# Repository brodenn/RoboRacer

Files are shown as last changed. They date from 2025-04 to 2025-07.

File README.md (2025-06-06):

# RoboRacer

## 📄 [Download the full report: Report ghost divsion.pdf](./Report%20ghost%20divsion.pdf)

Welcome to the RoboRacer project! This repository contains the full stack for the Omnix robot platform, including embedded firmware, Python-based visualization and configuration tools, and supporting documentation.

---

## Project Images

### Robots
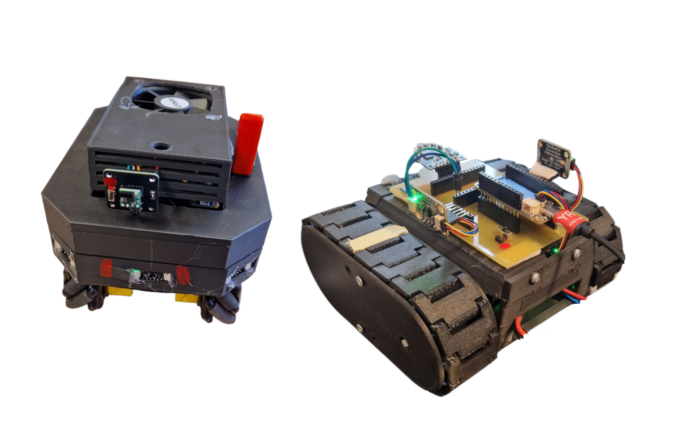
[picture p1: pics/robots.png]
Robots


---

# Omnix Overview

The `omnix` robot is a core vehicle in the RoboRacer project, equipped with omni wheels for enhanced maneuverability. It handles sensor management, motor control, AI steering, and wireless communication, and is supported by a Python toolkit for visualization and configuration.

---

## Directory Structure

- **`ai.cpp` / `ai.h`**: AI steering logic for autonomous navigation.
- **`controller.cpp` / `controller.h`**: Gamepad/controller input management.
- **`globals.cpp` / `globals.h`**: Global variables and constants.
- **`imu.cpp` / `imu.h`**: IMU (Inertial Measurement Unit) initialization and data reading.
- **`interrupts.cpp` / `interrupts.h`**: Sensor interrupt configuration and management.
- **`motors.cpp` / `motors.h`**: Motor initialization and control.
- **`mux.cpp` / `mux.h`**: I2C multiplexer for sensor communication.
- **`params.cpp` / `params.h`**: Steering and sensor parameter management.
- **`sensors.cpp` / `sensors.h`**: Sensor initialization, reading, and management.
- **`tasks.cpp` / `tasks.h`**: FreeRTOS tasks for sensors, motors, and logic.
- **`udp_handler.cpp` / `udp_comm.h`**: UDP communication for parameters and telemetry.
- **`udp_sender.cpp`**: Telemetry data transmission over UDP.
- **`wifi_setup.cpp` / `wifi_setup.h`**: WiFi and UDP setup.
- **`xshut.cpp` / `xshut.h`**: Sensor power control via GPIO.
- **`omnix_py/`**: Python scripts for visualization, configuration, and debugging.

---

## Python Toolkit Overview

The `omnix_py` directory provides Python scripts that complement the robot's firmware:

- **`main.py`**: Entry point for the Python tools (UI and visualizer).
- **`udp_comm.py`**: UDP communication for telemetry and commands.
- **`ui.py`**: Tkinter-based GUI for parameter tuning and monitoring.
- **`visualizer.py`**: Pygame-based visualization of sensor and IMU data.
- **`config.py`**: Shared configuration (ports, IPs, parameters).
- **`logger.py`**: Telemetry and sensor data logging to CSV.

---

## Key Features

- **Omni Wheels**: Smooth, precise movement in any direction.
- **Sensor Management**: Multiple VL53L4CD sensors via I2C multiplexers.
- **Motor Control**: Smooth updates and autonomous driving logic.
- **AI Steering**: Wall centering, curve anticipation, and obstacle avoidance.
- **Wireless Communication**: Real-time telemetry and parameter updates via UDP.
- **IMU Integration**: Acceleration, gyroscope, and temperature data.
- **Python Tools**: UI for parameter tuning and real-time telemetry visualization.

---

## Setup Instructions

1. Initialize the I2C buses and configure the multiplexer.
2. Set up sensors, motors, and WiFi.
3. Start FreeRTOS tasks for sensor reading, motor control, and auxiliary logic.
4. Run the Python tools using `python3 main.py` in the `omnix_py` directory.

---

## Usage

- **Autonomous Mode**: AI steering logic controls the motors based on sensor data.
- **Controller Mode**: Use a gamepad for manual control.
- **Python Tools**: Tune parameters and monitor telemetry in real time.

---

## Dependencies

- [ArduinoJson](https://arduinojson.org/)
- [Adafruit Motor Shield Library](https://github.com/adafruit/Adafruit_Motor_Shield_V2_Library)
- [Adafruit LSM6DSOX Library](https://github.com/adafruit/Adafruit_LSM6DSOX)
- [Bluepad32](https://github.com/ricardoquesada/Bluepad32)
- [VL53L4CD Library](https://github.com/stm32duino/VL53L4CD)
- **Python**: Requires Python 3.8+ with the following libraries:
  - `pygame`
  - `tkinter`
  - `socket`
  - `json`
  - `csv`

---

## Visualizer Example

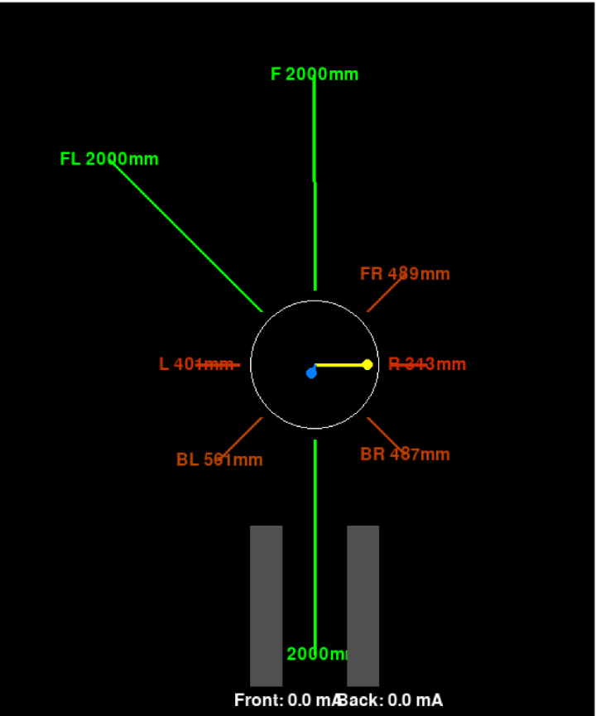
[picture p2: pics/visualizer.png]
Visualizer


---

## Configuration GUI

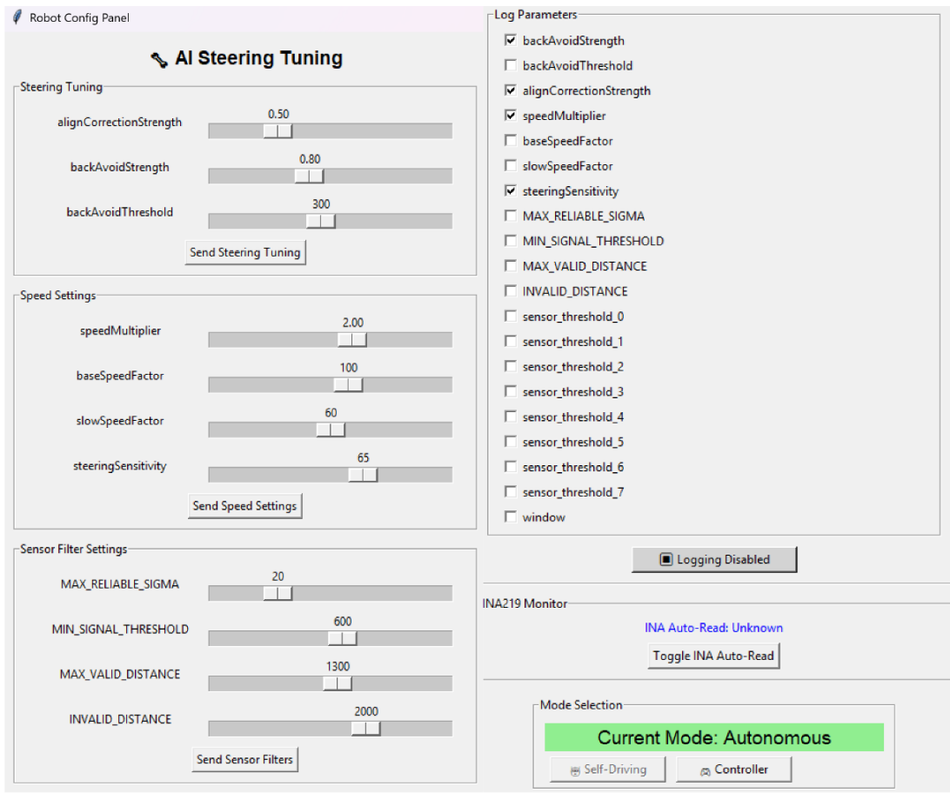
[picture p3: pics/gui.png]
GUI


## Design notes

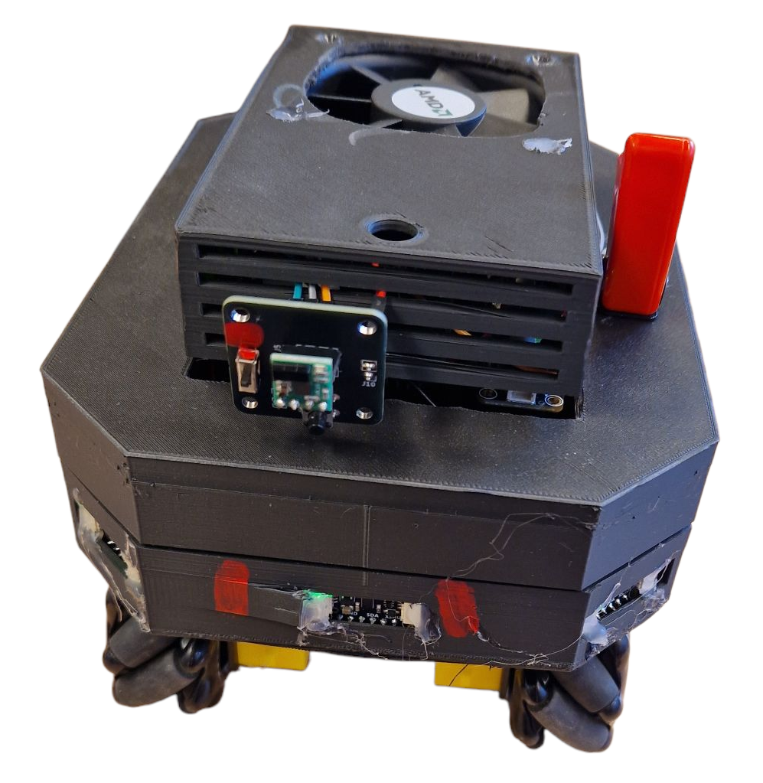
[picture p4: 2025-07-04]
omnix/Omni-X.png

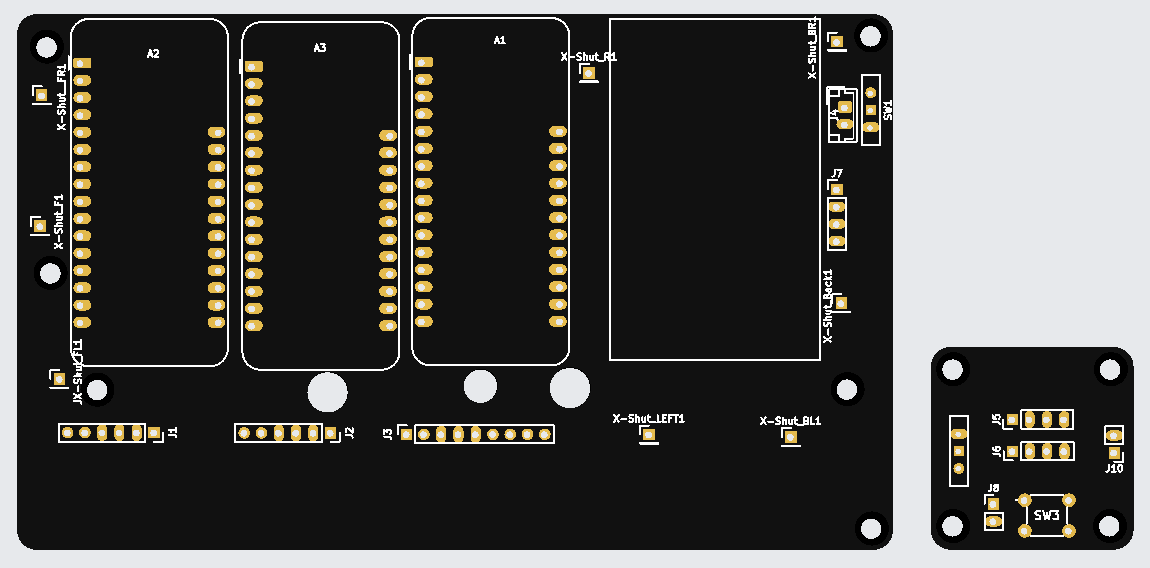
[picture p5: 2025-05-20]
Omni_X-PCB/Screenshot 2025-05-19 212435.png

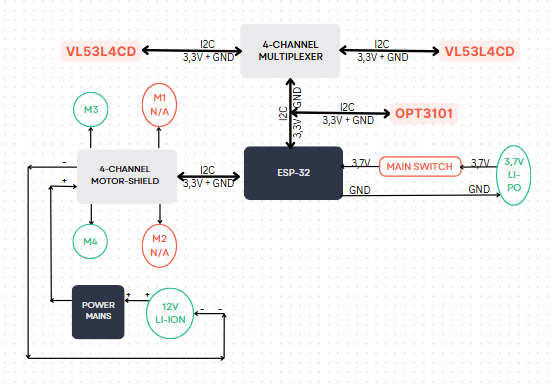
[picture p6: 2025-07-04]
omnix/Panzer_Connection_layout.png

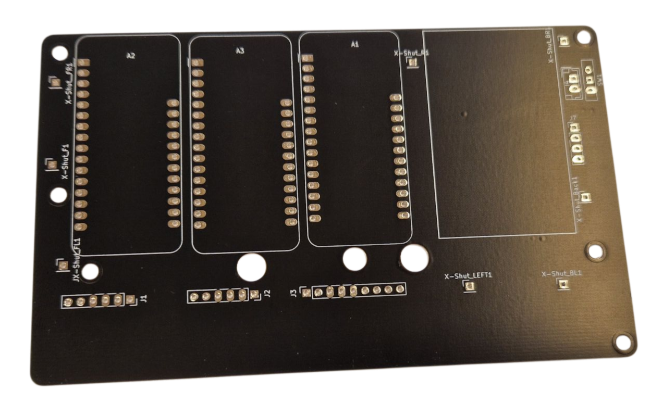
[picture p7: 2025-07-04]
omnix/Omni-X_PCB.png

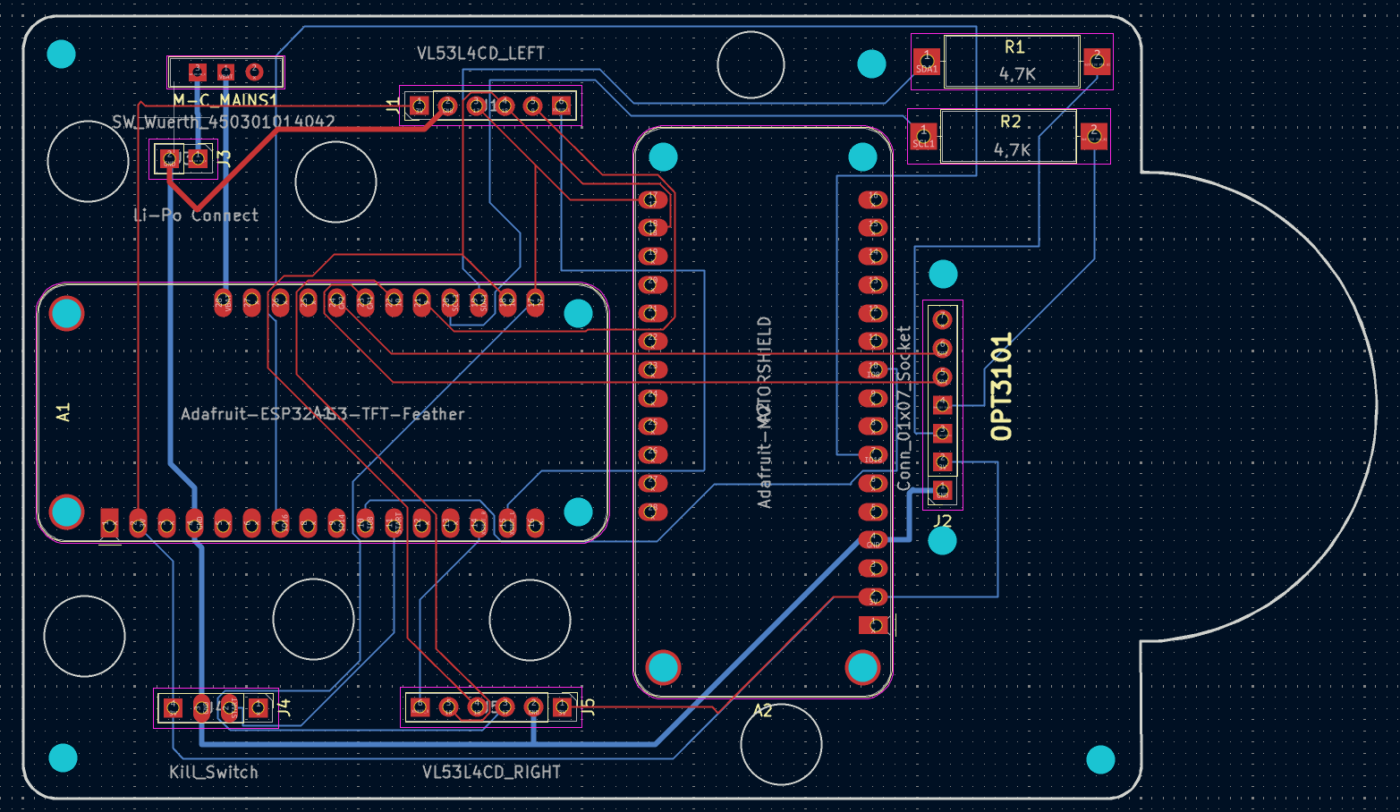
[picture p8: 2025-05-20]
Panzer/Panzer_PCB/Panzer_PCB/Screenshot 2025-05-19 212106.png

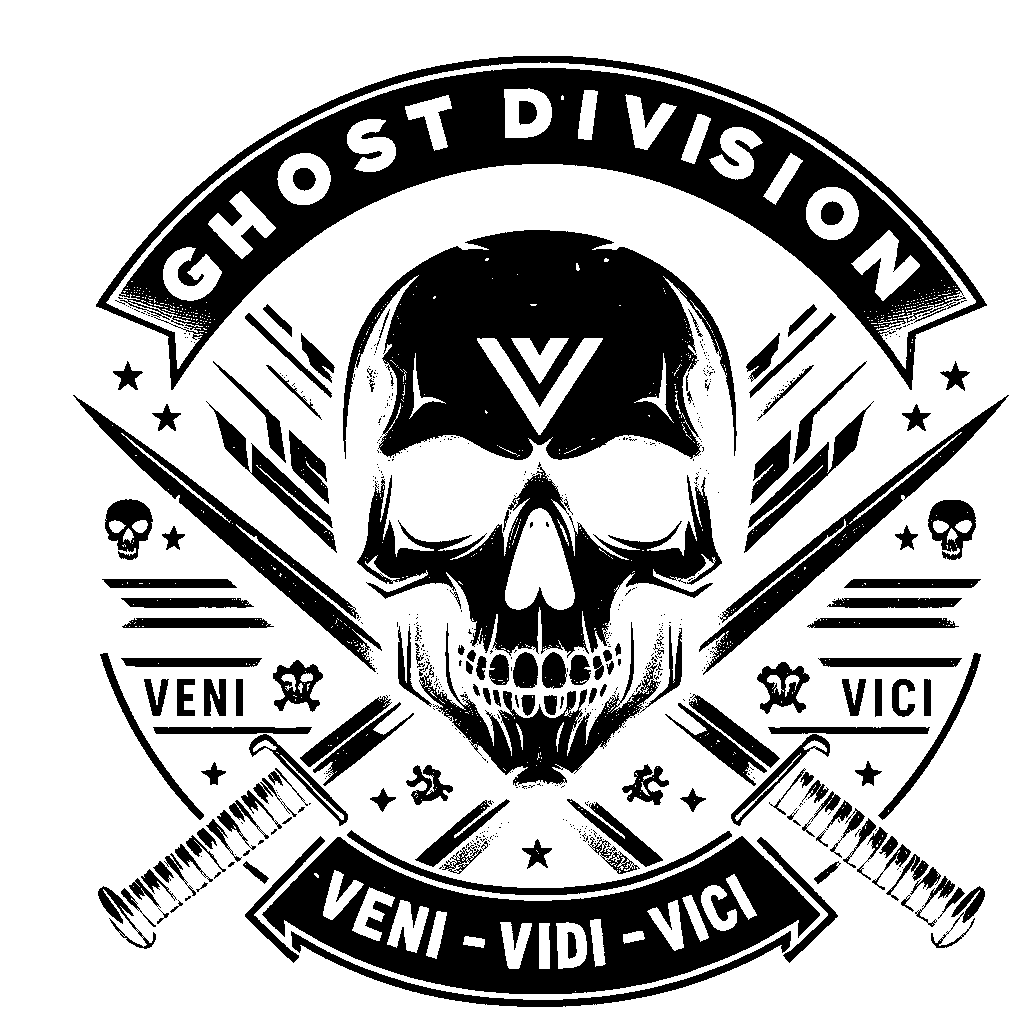
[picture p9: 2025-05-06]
Omni_X-PCB/Omni-X-II-PCB/ghost_division_bw.png

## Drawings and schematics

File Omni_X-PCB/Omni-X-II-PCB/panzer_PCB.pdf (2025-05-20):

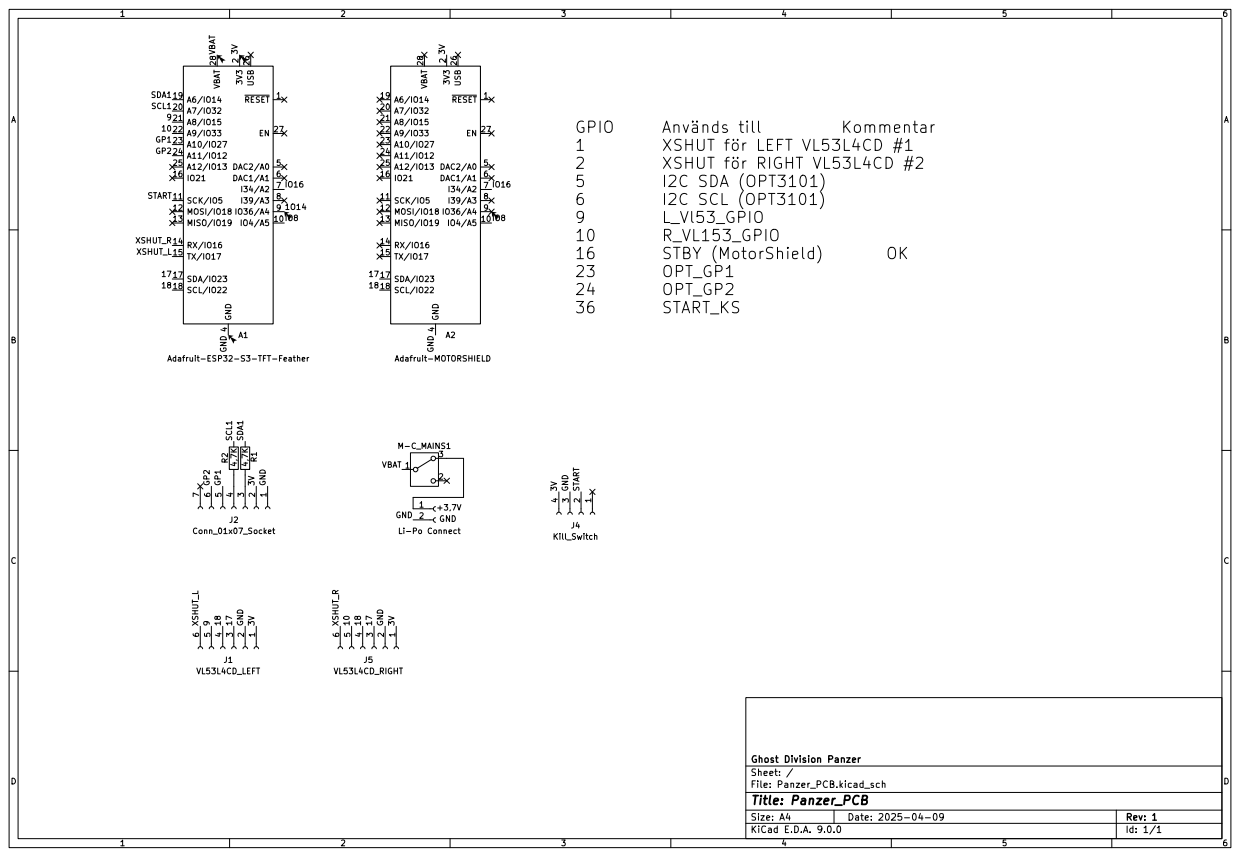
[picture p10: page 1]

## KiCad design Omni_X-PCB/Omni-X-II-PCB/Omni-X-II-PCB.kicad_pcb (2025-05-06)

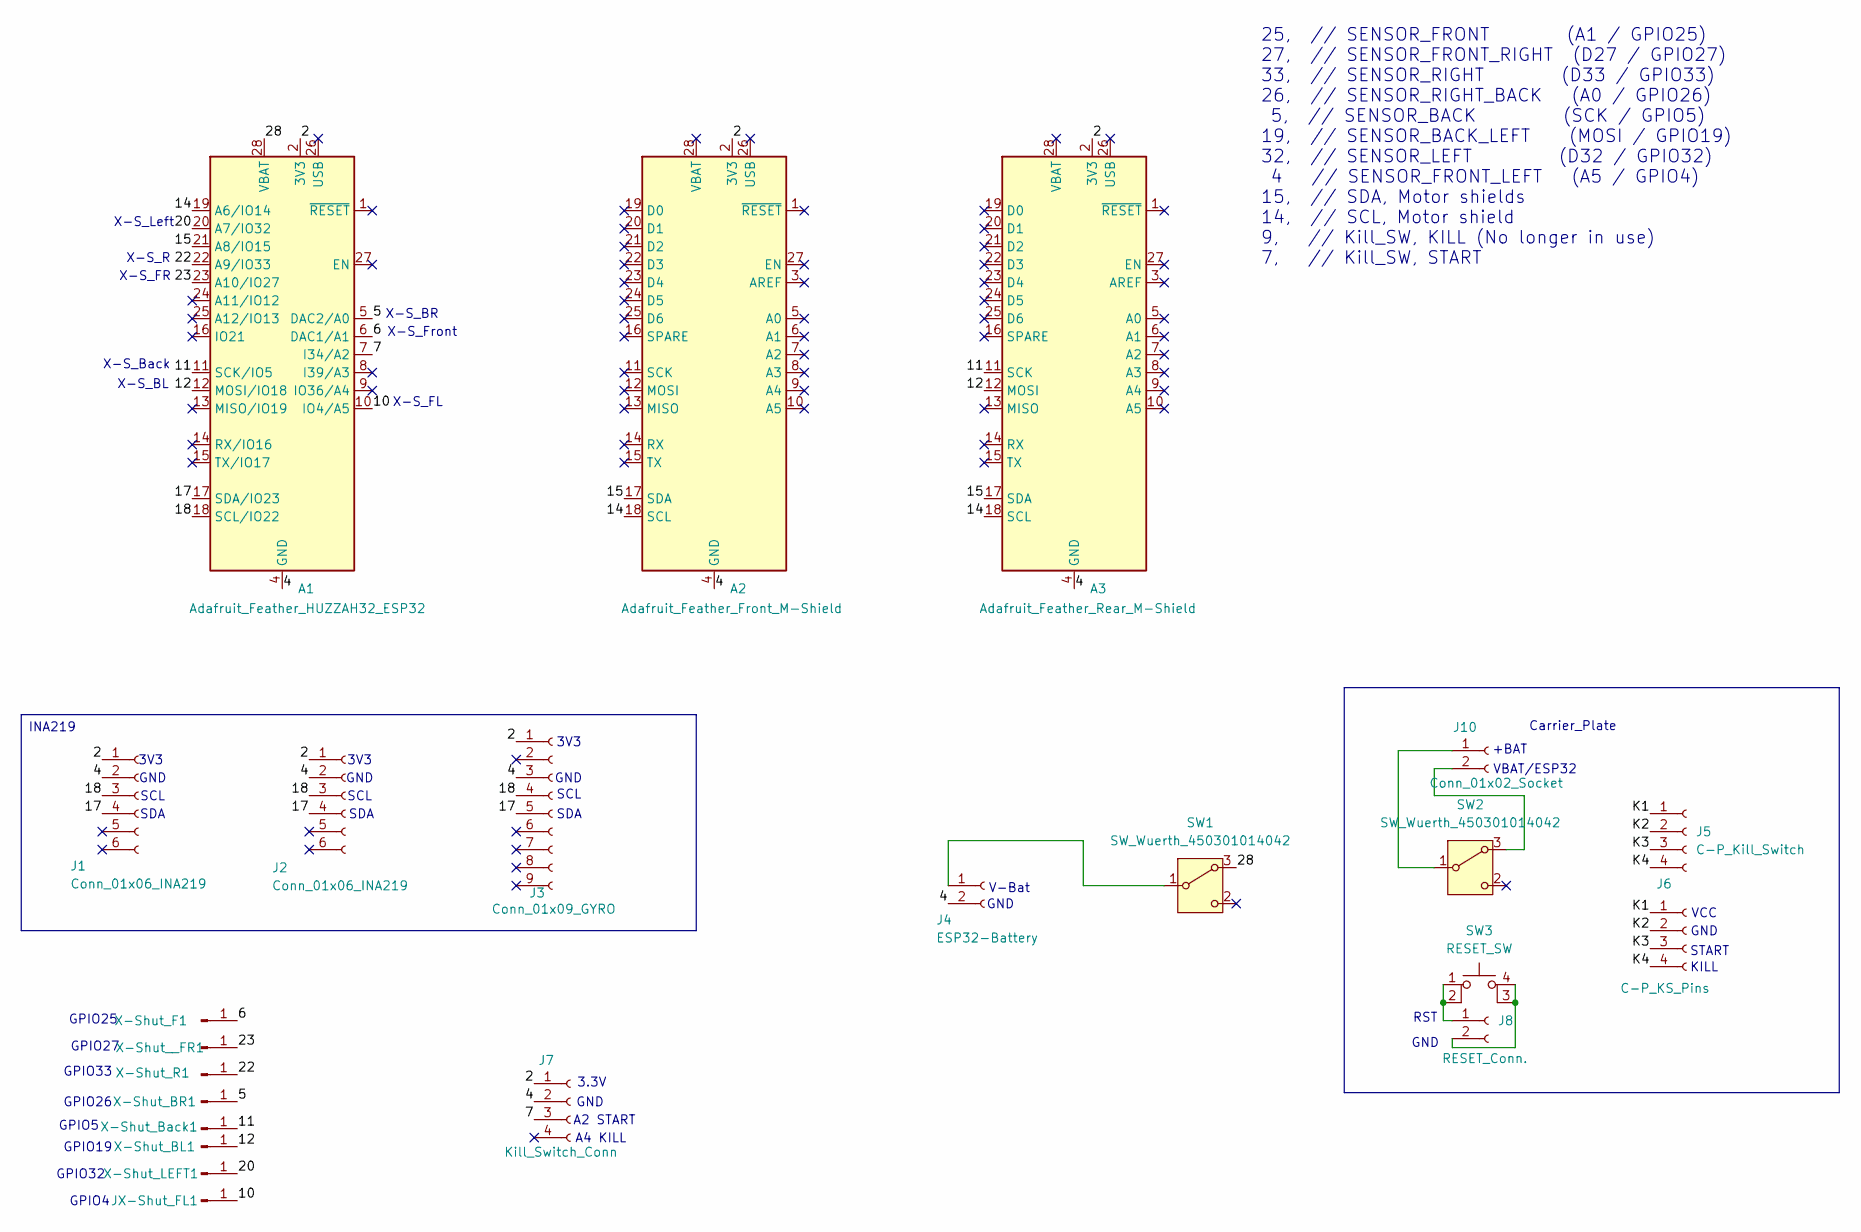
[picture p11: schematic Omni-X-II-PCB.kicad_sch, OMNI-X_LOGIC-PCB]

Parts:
A1: Adafruit_Feather_HUZZAH32_ESP32; Adafruit_Feather
A2: Adafruit_Feather_Front_M-Shield; Adafruit_Feather
A3: Adafruit_Feather_Rear_M-Shield; Adafruit_Feather
J1, J2: Conn_01x06_INA219; PinSocket_1x06_P2.54mm_Vertical
J3: Conn_01x09_GYRO; PinSocket_1x09_P2.54mm_Vertical
J4: ESP32-Battery; JST_EH_B2B-EH-A_1x02_P2.50mm_Vertical
J5: C-P_Kill_Switch; PinHeader_1x04_P2.54mm_Vertical
J6: C-P_KS_Pins; PinHeader_1x04_P2.54mm_Vertical
J7: Kill_Switch_Conn; PinHeader_1x04_P2.54mm_Vertical
J8: RESET_Conn.; PinHeader_1x02_P2.54mm_Vertical
J10: Conn_01x02_Socket; PinHeader_1x02_P2.54mm_Vertical
JX-Shut_FL1: Conn_01x01_Pin; PinHeader_1x01_P2.54mm_Vertical
SW1, SW2: SW_Wuerth_450301014042; SW_Slide-03_Wuerth-WS-SLTV_10x2.5x6.4_P2.54mm
SW3: RESET_SW; Tac_Switch_THT
X-Shut_BL1: Conn_01x01_Pin; PinHeader_1x01_P2.54mm_Vertical
X-Shut_BR1: Conn_01x01_Pin; PinHeader_1x01_P2.54mm_Vertical
X-Shut_Back1: Conn_01x01_Pin; PinHeader_1x01_P2.54mm_Vertical
X-Shut_F1: Conn_01x01_Pin; PinHeader_1x01_P2.54mm_Vertical
X-Shut_LEFT1: Conn_01x01_Pin; PinHeader_1x01_P2.54mm_Vertical
X-Shut_R1: Conn_01x01_Pin; PinHeader_1x01_P2.54mm_Vertical
X-Shut__FR1: Conn_01x01_Pin; PinHeader_1x01_P2.54mm_Vertical

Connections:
/2: A1.2 (3V3), A2.2 (3V3), A3.2 (3V3), J1.1, J2.1, J3.1, J7.1
/4: A1.4 (GND), A2.4 (GND), A3.4 (GND), J1.2, J2.2, J3.3, J4.2, J7.2
/5: A1.5 (DAC2/A0), X-Shut_BR1.1
/6: A1.6 (DAC1/A1), X-Shut_F1.1
/7: A1.7 (I34/A2), J7.3
/10: A1.10 (IO4/A5), JX-Shut_FL1.1
/11: A1.11 (SCK/IO5), A3.11 (SCK), X-Shut_Back1.1
/12: A1.12 (MOSI/IO18), A3.12 (MOSI), X-Shut_BL1.1
/14: A1.19 (A6/IO14), A2.18 (SCL), A3.18 (SCL)
/15: A1.21 (A8/IO15), A2.17 (SDA), A3.17 (SDA)
/17: A1.17 (SDA/IO23), J1.4, J2.4, J3.5
/18: A1.18 (SCL/IO22), J1.3, J2.3, J3.4
/20: A1.20 (A7/IO32), X-Shut_LEFT1.1
/22: A1.22 (A9/IO33), X-Shut_R1.1
/23: A1.23 (A10/IO27), X-Shut__FR1.1
/28: A1.28 (VBAT), SW1.3 (A)
/K1: J5.1, J6.1
/K2: J5.2, J6.2
/K3: J5.3, J6.3
/K4: J5.4, J6.4
unnamed: J4.1, SW1.1 (B)
unnamed: J8.1, SW3.1, SW3.2
unnamed: J8.2, SW3.3 (K), SW3.4 (A)
unnamed: J10.1, SW2.1 (B)
unnamed: J10.2, SW2.3 (A)

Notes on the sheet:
GPIO33
KILL
X-S_Front
X-S_R
X-S_BL
X-S_BR
RST
START
A2 START
X-S_FL
GPIO19
GND
SCL
GPIO4
A4 KILL
25, // SENSOR_FRONT (A1 / GPIO25) 27, // SENSOR_FRONT_RIGHT (D27 / GPIO27) 33, // SENSOR_RIGHT (D33 / GPIO33) 26, // SENSOR_RIGHT_BACK (A0 / GPIO26) 5, // SENSOR_BACK (SCK / GPIO5) 19, // SENSOR_BACK_LEFT (MOSI / GPIO19) 32, // SENSOR_LEFT (D32 / GPIO32) 4 // SENSOR_FRONT_LEFT (A5 / GPIO4) 15, // S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
VCC
GPIO26
SDA
VBAT/ESP32
3V3
GPIO32
V-Bat
X-S_FR
X-S_Left
X-S_Back
GPIO27
Carrier_Plate
+BAT
GPIO25
3.3V
GPIO5
INA219

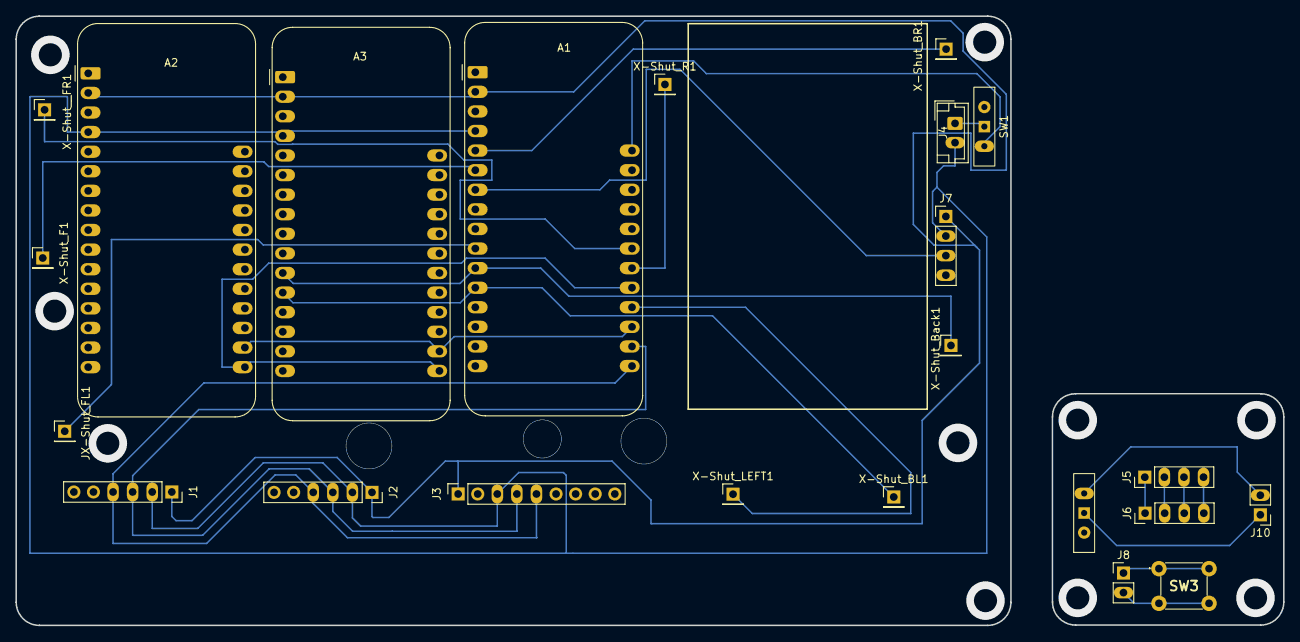
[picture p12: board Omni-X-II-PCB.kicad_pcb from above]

Board: 2 copper layers, 164.4 x 79.0 mm, 23 parts (0 on the bottom side), 25 nets.

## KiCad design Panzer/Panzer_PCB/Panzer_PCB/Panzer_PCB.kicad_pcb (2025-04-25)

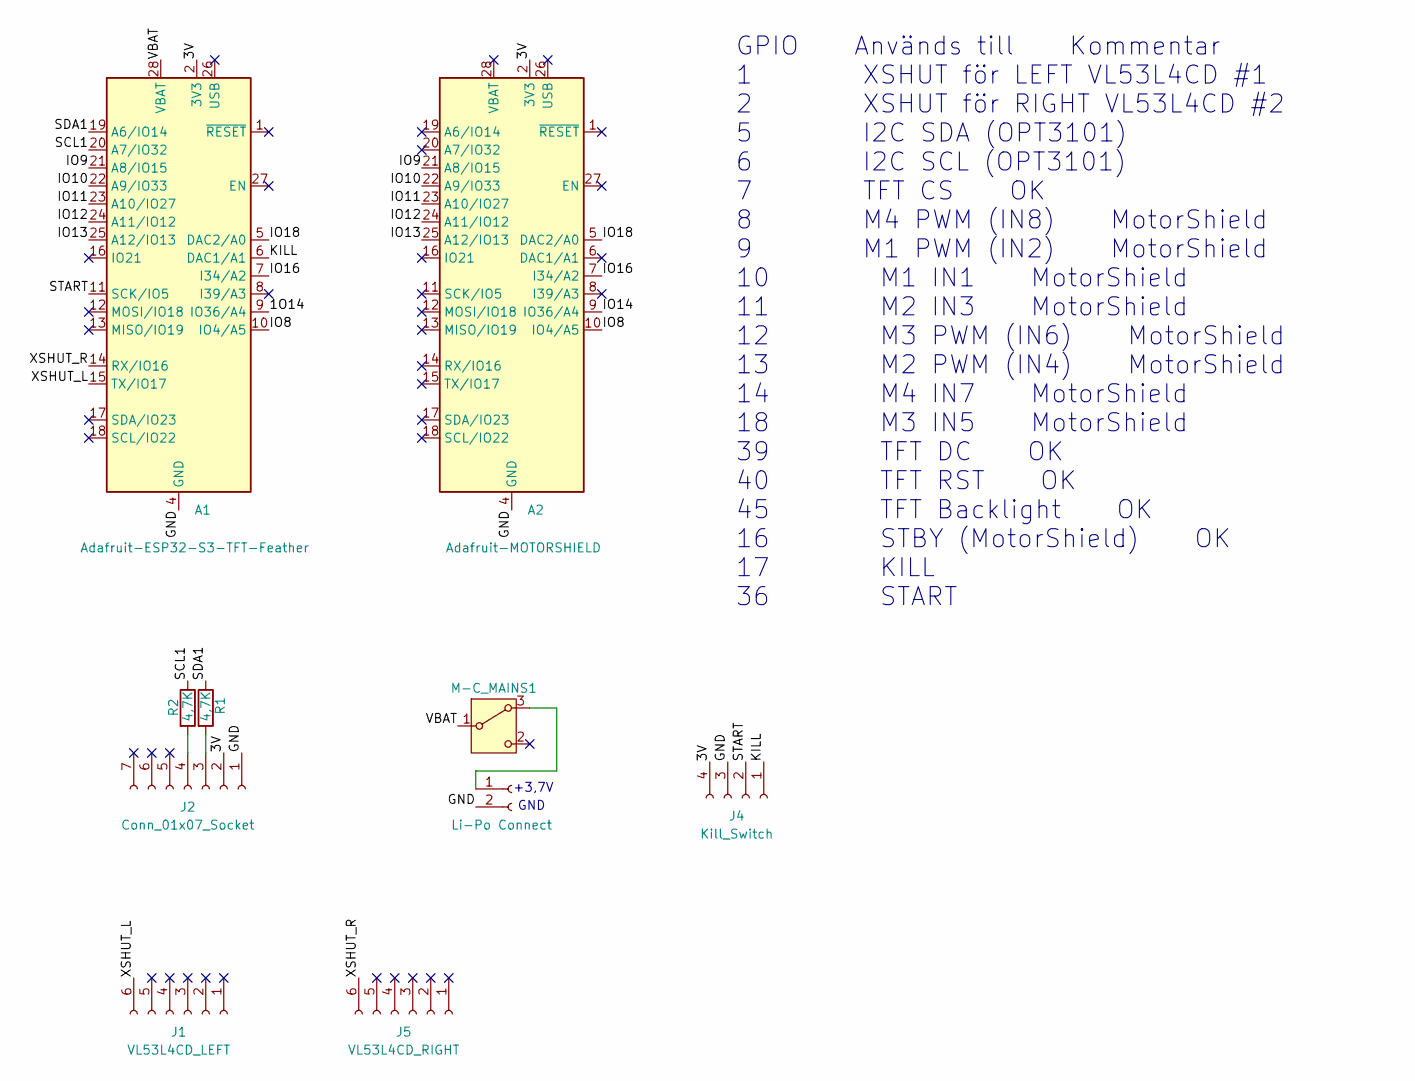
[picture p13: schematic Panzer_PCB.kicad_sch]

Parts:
A1: Adafruit-ESP32-S3-TFT-Feather; Adafruit_Feather_WithMountingHoles
A2: Adafruit-MOTORSHIELD; Adafruit_Feather_WithMountingHoles
J1: VL53L4CD_LEFT; PinHeader_1x06_P2.54mm_Vertical
J2: Conn_01x07_Socket; PinSocket_1x07_P2.54mm_Vertical
J3: Li-Po Connect; PinHeader_1x02_P2.54mm_Vertical
J4: Kill_Switch; PinHeader_1x04_P2.54mm_Vertical
J5: VL53L4CD_RIGHT; PinHeader_1x06_P2.54mm_Vertical
M-C_MAINS1: SW_Wuerth_450301014042; SW_Slide-03_Wuerth-WS-SLTV_10x2.5x6.4_P2.54mm
R1, R2: 4,7K; R_Axial_DIN0414_L11.9mm_D4.5mm_P15.24mm_Horizontal

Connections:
/1O14: A1.9 (IO36/A4)
/3V: A1.2 (3V3), A2.2 (3V3), J2.2, J4.4
/GND: A1.4 (GND), A2.4 (GND), J2.1, J3.2, J4.3
/IO8: A1.10 (IO4/A5), A2.10 (IO4/A5)
/IO9: A1.21 (A8/IO15), A2.21 (A8/IO15)
/IO10: A1.22 (A9/IO33), A2.22 (A9/IO33)
/IO11: A1.23 (A10/IO27), A2.23 (A10/IO27)
/IO12: A1.24 (A11/IO12), A2.24 (A11/IO12)
/IO13: A1.25 (A12/IO13), A2.25 (A12/IO13)
/IO14: A2.9 (IO36/A4)
/IO16: A1.7 (I34/A2), A2.7 (I34/A2)
/IO18: A1.5 (DAC2/A0), A2.5 (DAC2/A0)
/KILL: A1.6 (DAC1/A1), J4.1
/SCL1: A1.20 (A7/IO32), R2.1
/SDA1: A1.19 (A6/IO14), R1.1
/START: A1.11 (SCK/IO5), J4.2
/VBAT: A1.28 (VBAT), M-C_MAINS1.1 (B); also elsewhere on the board
/XSHUT_L: A1.15 (TX/IO17), J1.6
/XSHUT_R: A1.14 (RX/IO16), J5.6
unnamed: J2.3, R1.2
unnamed: J2.4, R2.2
unnamed 21: J3.1, M-C_MAINS1.3 (A); also elsewhere on the board

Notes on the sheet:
+3,7V
GND
GPIO Används till Kommentar 1 XSHUT för LEFT VL53L4CD #1 2 XSHUT för RIGHT VL53L4CD #2 5 I2C SDA (OPT3101) 6 I2C SCL (OPT3101) 7 TFT CS OK 8 M4 PWM (IN8) MotorShield 9 M1 PWM (IN2) MotorShield 10 M1 IN1 MotorShield 11 M2 IN3 MotorShield 12 M3 PWM (IN6) MotorShield 13 M2 PWM (IN4) MotorShield 14 M4 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

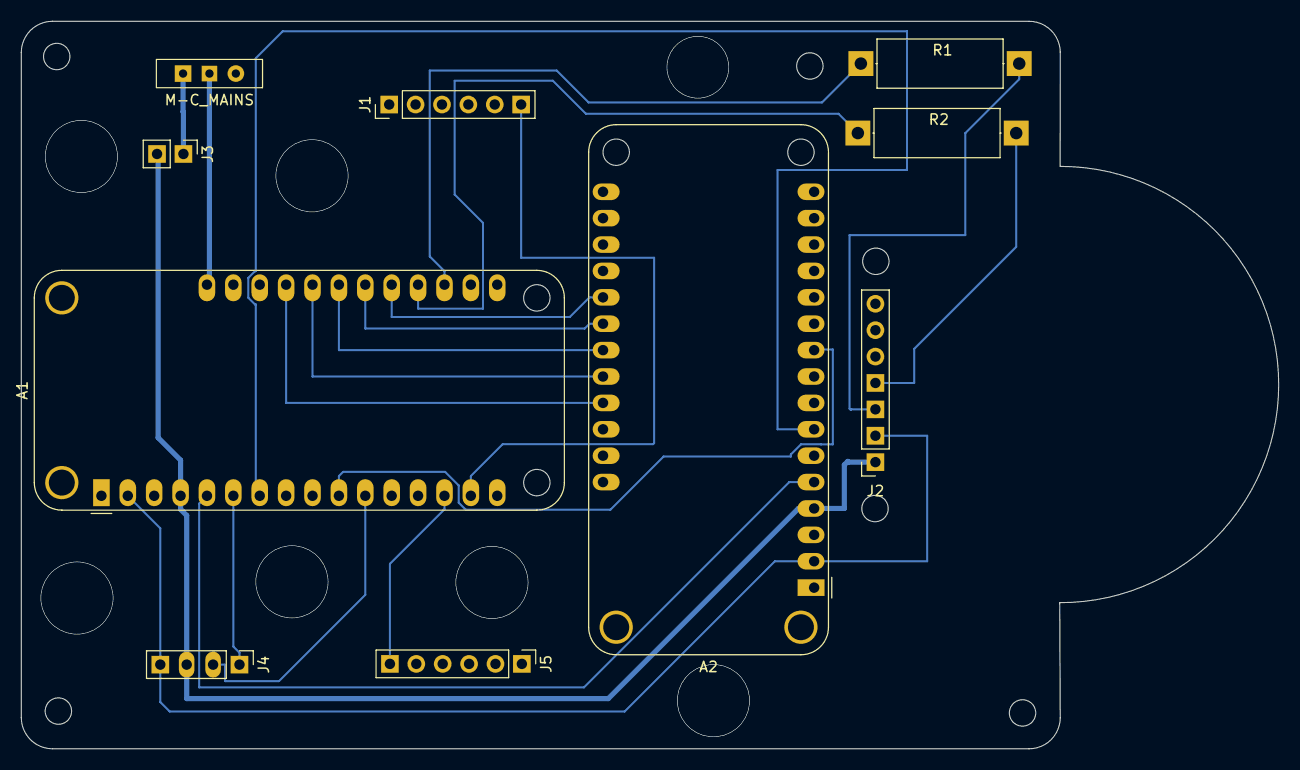
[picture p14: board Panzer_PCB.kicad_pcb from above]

Board: 2 copper layers, 121.0 x 70.0 mm, 10 parts (0 on the bottom side), 20 nets.

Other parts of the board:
M-C_MAINS: SW_Wuerth_450301014042; SW_Slide-03_Wuerth-WS-SLTV_10x2.5x6.4_P2.54mm

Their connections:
/VBAT: M-C_MAINS.1 (B); also elsewhere on the board
unnamed 21: M-C_MAINS.3 (A); also elsewhere on the board

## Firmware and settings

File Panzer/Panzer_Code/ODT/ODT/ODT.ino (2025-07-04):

#include <Arduino.h>
#include <Wire.h>
#include <Adafruit_MotorShield.h>
#include <ArduinoOTA.h>
#include <WebSerial.h>

#include "ota.h"
#include "mux.h"
#include "opt.h"
#include "tft.h"
#include "evade.h"
#include "steering.h"

// === Motorer ===
Adafruit_MotorShield AFMS = Adafruit_MotorShield(0x60);
Adafruit_DCMotor* motorLeft;
Adafruit_DCMotor* motorRight;

unsigned long avoidUntil = 0;
bool isAutoMode = true;
bool isWebSocketDataEnabled = true;

void setup() {
  Serial.begin(115200);
  delay(1000);

  setupWiFiAndOTA();       // WiFi och OTA
  Wire.begin();            // SDA = GPIO5, SCL = GPIO6

  // Init motor shield
  if (!AFMS.begin()) {
    Serial.println("❌ Kunde inte starta Motor FeatherWing!");
    while (1);
  }
  Serial.println("✅ Motor FeatherWing OK");

  motorLeft  = AFMS.getMotor(3);
  motorRight = AFMS.getMotor(4);

  initOPT();
  initVL53Sensors();
  initTFT();
}

void loop() {
  ArduinoOTA.handle();

  // === Sensoravläsning ===
  readOPTSensors();
  checkVL53Obstacles();
  updateTFT();

  // === WebSocket & WebSerial-uppdatering ===
  static unsigned long lastSend = 0;
  static unsigned long lastCleanup = 0;
  const unsigned long sendInterval = 200;  // Ändra till 100 om du vill testa igen
  const unsigned long cleanupInterval = 1000;

  if (millis() - lastSend >= sendInterval) {
    lastSend = millis();

    if (isWebSocketDataEnabled) {
      int pwmL_pct = map(currentPWM_L, 0, 255, 0, 100);
      int pwmR_pct = map(currentPWM_R, 0, 255, 0, 100);
      if (dirLeftForward) pwmL_pct *= -1;
      if (!dirRightForward) pwmR_pct *= -1;

      String msg = "sensor:" +
                   String(vl53Distances[0]) + "," +
                   String(optDistances[0]) + "," +
                   String(optDistances[1]) + "," +
                   String(optDistances[2]) + "," +
                   String(vl53Distances[1]) + "," +
                   String(currentPWM_L) + "," +
                   String(currentPWM_R) + "," +
                   String(pwmL_pct) + "," +
                   String(pwmR_pct);

      ws.textAll(msg);
      WebSerial.println(msg);

      Serial.print("PWM L: ");
      Serial.print(pwmL_pct);
      Serial.print("%  |  PWM R: ");
      Serial.print(pwmR_pct);
      Serial.println("%");
    }
  }

  // === WebSocket-klient-rensning ===
  if (millis() - lastCleanup >= cleanupInterval) {
    lastCleanup = millis();
    ws.cleanupClients();
  }

  // === AUTO-läge ===
  if (isAutoMode) {
    bool frontBlocked = optDistances[1] < 300;
    bool sideBlockedL = vl53Distances[0] > 0 && vl53Distances[0] < 100;
    bool sideBlockedR = vl53Distances[1] > 0 && vl53Distances[1] < 100;

    Serial.println("🔁 AUTO-läge körs");

    if (frontBlocked || sideBlockedL || sideBlockedR) {
      performAvoidance(
        vl53Distances[0], optDistances[0], optDistances[2], vl53Distances[1], optDistances[1]
      );
    } else {
      correctCourse();
    }
  }
}

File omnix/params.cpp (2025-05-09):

#include <ArduinoJson.h>
#include "params.h"
#include "globals.h"
#include "mux.h"

// ✅ Global definition (single instance)
SteeringParams params;

void SteeringParams::loadFromJson(JsonDocument& doc) {
    auto update = [](float& var, const char* key, JsonDocument& doc) {
        if (doc.containsKey(key)) {
            float newVal = doc[key];
            if (var != newVal) {
                Serial.printf("🔧 %s changed: %.2f -> %.2f\n", key, var, newVal);
                var = newVal;
            }
        }
    };

    auto updateInt = [](int& var, const char* key, JsonDocument& doc) {
        if (doc.containsKey(key)) {
            int newVal = doc[key];
            if (var != newVal) {
                Serial.printf("🔧 %s changed: %d -> %d\n", key, var, newVal);
                var = newVal;
            }
        }
    };

    auto updateBool = [](bool& var, const char* key, JsonDocument& doc) {
        if (doc.containsKey(key)) {
            bool newVal = doc[key];
            if (var != newVal) {
                Serial.printf("🔧 %s changed: %s -> %s\n", key, var ? "true" : "false", newVal ? "true" : "false");
                var = newVal;
            }
        }
    };

    // === Sensor filtering & fault handling ===
    updateInt(MAX_RELIABLE_SIGMA,   "MAX_RELIABLE_SIGMA",   doc);
    updateInt(MIN_SIGNAL_THRESHOLD, "MIN_SIGNAL_THRESHOLD", doc);
    updateInt(MAX_VALID_DISTANCE,   "MAX_VALID_DISTANCE",   doc);
    updateInt(INVALID_DISTANCE,     "INVALID_DISTANCE",     doc);
    updateInt(softFailLimit,        "softFailLimit",        doc);
    updateBool(sensorRestartEnabled,"sensorRestartEnabled", doc);

    // === Detection thresholds ===
    updateInt(threshold_front, "threshold_front", doc);
    updateInt(threshold_side,  "threshold_side",  doc);
    updateInt(threshold_back,  "threshold_back",  doc);

    // === Rear tuning (alignment / avoidance) ===
    update(backAvoidStrength,        "backAvoidStrength",        doc);
    update(alignCorrectionStrength,  "alignCorrectionStrength",  doc);
    updateInt(backAvoidThreshold,    "backAvoidThreshold",       doc);

    // === Speed & steering tuning ===
    update(baseSpeedFactor,           "baseSpeedFactor",           doc);
    update(slowSpeedFactor,           "slowSpeedFactor",           doc);
    update(speedMultiplier,           "speedMultiplier",           doc);
    update(centeringStrength,         "centeringStrength",         doc);
    update(curveAnticipationStrength, "curveAnticipationStrength", doc);
    update(steeringSensitivity,       "steeringSensitivity",       doc);

    // === Window mode (interrupt config) ===
    updateInt(windowMode, "windowMode", doc);

    // === Per-sensor dynamic thresholding ===
    if (doc.containsKey("thresholds")) {
        JsonObject thresholds = doc["thresholds"];
        int overrideWindow = doc["window"] | windowMode;

        for (uint8_t i = 0; i < NUM_SENSORS; i++) {
            if (!thresholds.containsKey(String(i))) continue;

            uint16_t high = thresholds[String(i)];

            deselectAllMux();
            delayMicroseconds(200);
            selectMuxChannel(i);
            delayMicroseconds(400);

            if (xSemaphoreTake(i2cBusyWire0, pdMS_TO_TICKS(30))) {
                sensor.VL53L4CD_SetDetectionThresholds(0, high, overrideWindow);
                xSemaphoreGive(i2cBusyWire0);
                Serial.printf("📏 Sensor %d: Detection threshold set to %d mm (window=%d)\n", i, high, overrideWindow);
            }
        }
    }
}

void applyThresholdsToSensors() {
    for (uint8_t i = 0; i < NUM_SENSORS; i++) {
        uint16_t high = (i == 0) ? params.threshold_front :
                        (i == 3 || i == 4 || i == 5) ? params.threshold_back :
                        params.threshold_side;

        deselectAllMux();
        delayMicroseconds(200);
        selectMuxChannel(i);
        delayMicroseconds(400);

        if (xSemaphoreTake(i2cBusyWire0, pdMS_TO_TICKS(30))) {
            sensor.VL53L4CD_SetDetectionThresholds(0, high, params.windowMode);
            xSemaphoreGive(i2cBusyWire0);
            Serial.printf("📏 Sensor %d: Detection threshold set to %d mm (window=%d)\n", i, high, params.windowMode);
        }
    }
}
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

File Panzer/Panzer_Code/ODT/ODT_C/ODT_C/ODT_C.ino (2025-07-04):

#include <Arduino.h>                     // Grundläggande Arduino-funktioner
#include <Wire.h>                        // I2C-kommunikation
#include <Adafruit_MotorShield.h>        // Styrning av Adafruit Motor FeatherWing

#include "mux.h"                         // Multiplexer-hantering (VL53L4CD)
#include "opt.h"                         // OPT3101-sensorhantering
#include "tft.h"                         // TFT-displayhantering
#include "evade.h"                       // Hinderundvikningslogik
#include "steering.h"                    // Kurskorrigering

#define PIN_START 13

// === Globala motorobjekt ===
Adafruit_MotorShield AFMS = Adafruit_MotorShield(0x60);  // Motor FeatherWing på I2C-adress 0x60
Adafruit_DCMotor* motorLeft;                             // Vänster motor (M3)
Adafruit_DCMotor* motorRight;                            // Höger motor (M4)

unsigned long avoidUntil = 0;  // Variabel för att hålla koll på hur länge vi ska undvika hinder

void setup() {
  Serial.begin(115200);       // Startar seriell kommunikation
  delay(1000);                // Kort delay för stabil uppstart

  // Initiera I2C-kommunikation på specifika GPIO-pinnar
  Wire.begin(5, 6);           // SDA = GPIO5, SCL = GPIO6

  // Initiera motorskölden
  if (!AFMS.begin()) {
    Serial.println("❌ Kunde inte starta Motor FeatherWing!");
    while (1);                // Stoppar systemet om motorskölden inte kan initieras
  }
  Serial.println("✅ Motor FeatherWing OK");

  // Hämta motorobjekt för M3 och M4
  motorLeft  = AFMS.getMotor(3);  // Motor M3 = vänster
  motorRight = AFMS.getMotor(4);  // Motor M4 = höger

  // Initiera sensorer
  initOPT();                // Starta OPT3101-sensorer
  initVL53Sensors();        // Initiera multiplexer och VL53-sensorer

  // Initiera TFT-display
  initTFT();                // Starta upp displayen
}

void loop() {

    while (digitalRead(PIN_START) == LOW) {
  int val = digitalRead(PIN_START);
  Serial.println(val == LOW ? "⬇️ Tryckt" : "⬆️ Släppt");
  delay(300);
}
  // === Läs sensordata ===
  readOPTSensors();            // Läs in avstånd från OPT3101: [0]=LEFT, [1]=FRONT, [2]=RIGHT
  checkVL53Obstacles();        // Läs in avstånd från VL53 via multiplexer: [0]=LEFT, [1]=RIGHT

  // === Uppdatera skärm ===
  updateTFT();                 // Visa sensorvärden på TFT-displayen

  // === Beslutslogik: kontrollera hinder ===
  bool frontBlocked = optDistances[1] < 300;                       // Hinder rakt fram (< 30 cm)
  bool sideBlockedL = vl53Distances[0] > 0 && vl53Distances[0] < 100;  // Hinder vänster (< 10 cm)
  bool sideBlockedR = vl53Distances[1] > 0 && vl53Distances[1] < 100;  // Hinder höger (< 10 cm)

  // === Hinderundvikning eller kurskorrigering ===
  if (frontBlocked || sideBlockedL || sideBlockedR) {
    performAvoidance(                       // Kör väjningslogik
      vl53Distances[0],                     // Vänster VL53
      vl53Distances[1],                     // Höger VL53
      optDistances[0],                      // Vänster OPT
      optDistances[2],                      // Höger OPT
      optDistances[1]                       // Front OPT
    );
  } else {
    correctCourse();                        // Kurskorrigering när fri väg framåt
  }

  delay(10);  // Stabiliserar loopfrekvens (~10 Hz)
}

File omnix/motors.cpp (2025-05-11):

#include "motors.h"
#include "globals.h"

bool motorShield60Found = false;
bool motorShield61Found = false;

void setupMotors() {
    if (xSemaphoreTake(i2cBusyWire1, pdMS_TO_TICKS(50)) == pdTRUE) {
        motorShield60Found = AFMS_60.begin(1600, &Wire1);
        motorShield61Found = AFMS_61.begin(1600, &Wire1);
        xSemaphoreGive(i2cBusyWire1);
    }

    Serial.println(motorShield60Found ? "✅ Motor Shield 0x60 detected" : "❌ Motor Shield 0x60 NOT found");
    Serial.println(motorShield61Found ? "✅ Motor Shield 0x61 detected" : "❌ Motor Shield 0x61 NOT found");

    motor1 = AFMS_61.getMotor(4);  // Right-Back
    motor2 = AFMS_60.getMotor(1);  // Front-Left
    motor3 = AFMS_60.getMotor(3);  // Left-Back
    motor4 = AFMS_61.getMotor(3);  // Front-Right
}

void smoothMotorUpdate() {
    static unsigned long lastUpdate = 0;
    if (millis() - lastUpdate < motorUpdateInterval) return;
    lastUpdate = millis();

    if (xSemaphoreTake(i2cBusyWire1, pdMS_TO_TICKS(10)) != pdTRUE) {
        Serial.println("⚠️ smoothMotorUpdate: Failed to acquire i2cBusyWire1");
        return;
    }

    int diffs[4] = {
        constrain(target_m1 - current_m1, -MAX_STEP, MAX_STEP),
        constrain(target_m2 - current_m2, -MAX_STEP, MAX_STEP),
        constrain(target_m3 - current_m3, -MAX_STEP, MAX_STEP),
        constrain(target_m4 - current_m4, -MAX_STEP, MAX_STEP)
    };

    if (diffs[0] == 0 && diffs[1] == 0 && diffs[2] == 0 && diffs[3] == 0) {
        xSemaphoreGive(i2cBusyWire1);
        return;
    }

    Adafruit_DCMotor* motors[4] = {motor1, motor2, motor3, motor4};
    int* targets[4]  = {&target_m1, &target_m2, &target_m3, &target_m4};
    int* currents[4] = {&current_m1, &current_m2, &current_m3, &current_m4};
    const char* labels[4] = {"M1 (RB)", "M2 (FL)", "M3 (LB)", "M4 (FR)"};

    for (int i = 0; i < 4; i++) {
        if (!motors[i]) continue;

        *currents[i] += diffs[i];
        int rawSpeed = *currents[i];
        int absSpeed = constrain(abs(rawSpeed), 0, 255);

        if (absSpeed == 0) {
            motors[i]->run(RELEASE);
            Serial.printf("🌀 %s: RELEASED (target=%d)\n", labels[i], *targets[i]);
        } else {
            bool forward = rawSpeed > 0;
            motors[i]->run(forward ? FORWARD : BACKWARD);
            motors[i]->setSpeed(absSpeed);
            Serial.printf("🌀 %s: Dir=%s Speed=%d Target=%d Current=%d\n",
                          labels[i], forward ? "FWD" : "BWD",
                          absSpeed, *targets[i], *currents[i]);
        }
    }

    xSemaphoreGive(i2cBusyWire1);
}



void checkMotorShields(bool doMotorTest) {
    if (xSemaphoreTake(i2cBusyWire1, pdMS_TO_TICKS(100)) == pdTRUE) {
        motorShield60Found = AFMS_60.begin(1600, &Wire1);
        motorShield61Found = AFMS_61.begin(1600, &Wire1);
        xSemaphoreGive(i2cBusyWire1);
    }

    Serial.println(motorShield60Found ? "✅ Re-check: Shield 0x60 OK" : "❌ Re-check: Shield 0x60 MISSING");
    Serial.println(motorShield61Found ? "✅ Re-check: Shield 0x61 OK" : "❌ Re-check: Shield 0x61 MISSING");

    motor1 = AFMS_61.getMotor(4);
    motor2 = AFMS_60.getMotor(1);
    motor3 = AFMS_60.getMotor(3);
    motor4 = AFMS_61.getMotor(3);

    if (doMotorTest) {
        Adafruit_DCMotor* motors[4] = {motor1, motor2, motor3, motor4};
        const char* labels[4] = {"Right-Back", "Front-Left", "Left-Back", "Front-Right"};

        for (int i = 0; i < 4; i++) {
            if (!motors[i]) continue;
            Serial.printf("🔁 Testing %s motor FORWARD...\n", labels[i]);
            motors[i]->run(FORWARD);
            motors[i]->setSpeed(150);
            delay(500);
            motors[i]->run(BACKWARD);
            motors[i]->setSpeed(150);
            delay(500);
            motors[i]->run(RELEASE);
            delay(200);
        }
    }
}

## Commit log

2025-04-25 Panzer Files
    [Panzer_PCB.kicad_pcb, Panzer_PCB.kicad_sch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]
2025-05-05 Refactor sensor mapping and update thresholds in mux.cpp and sensors.cpp
    - Updated sensor order in mux.cpp for improved clarity and consistency.
    - Adjusted threshold selection logic in sensors.cpp to ensure correct thresholds are applied based on sensor positions.
    - Enhanced fallback logic for unreliable sensor data in sensors.cpp.
    - Cleaned up comments for better understanding of the code flow.
    Optimize task priorities in omnix.ino
    - Changed the priority of the sensor task from 3 to 1 to improve system responsiveness.
    Add configuration and logging functionality in omnix_py
    - Introduced config.py to manage robot parameters and presets.
    - Implemented logger.py for structured logging of se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
    [controller.cpp, globals.cpp, mux.cpp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]
2025-05-05 Refactor and restructure project: removed visualizer.py, added config, logger, main, udp_comm, and ui modules
    - Deleted visualizer.py and integrated its functionality into a new structure.
    - Created config.py for centralized configuration management.
    - Implemented logger.py for logging functionality with CSV output.
    - Developed main.py to initialize and run the application with threading for UI and UDP communication.
    - Added udp_comm.py for handling UDP communication with the ESP32.
    - Introduced ui.py for a Tkinter-based user interface to control robot parameters and settings.
    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
2025-05-05 Updated panzer code
    Added OTA and webserver, Obstacle handling (rudimentary), sensor data retrieval logic.
2025-05-06 Omni_x-PCB
    PCB-files for Omnix-X
    [Omni-X-II-PCB-B_Cu.gbl, Omni-X-II-PCB-B_Cu.gbr, Omni-X-II-PCB-B_Mask.gbr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]
2025-05-09 Refactor code structure for improved readability and maintainability
    [ina_log.csv, robot_log_2025-05-08_13-15-03.csv]
2025-05-11 updated steering algorithm
2025-05-11 improved steering logic
2025-05-15 added steering algorythm using VL, non functional
